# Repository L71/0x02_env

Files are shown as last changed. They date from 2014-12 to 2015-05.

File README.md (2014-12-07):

0x02_env
========

Eurorack AD/ASR envelope and CV generator

This module generates a bipolar control voltage in response to a gate/trigger pulse.
The button selects how it responds to an input pulse: Attack-Decay or Attack-Sustain-Release. 
The zero and triggered (peak) levels are separately set anywhere within the output voltage range (-5 - +5 V).

** Work in progress **

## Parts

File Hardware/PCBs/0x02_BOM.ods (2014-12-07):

Qty | Value | Device | Parts | Description
6 | 100n | Ceramic capacitor 2.54mm | C1, C2, C4, C7, C11, C12
3 | 10u | Electrolytic capacitor. | C3, C5, C6 | Must not be more than 11mm high!
2 | 10n | Ceramic capacitor 2.54mm | C8, C9 | PWM filtering caps. 1-10nF OK. Lower value -> faster envelopes but more PWM leftovers.
2 | CV_OUT | AUDIO-JACKERTHENVAR | CV_OUT, GATE_THRU | Switching Mono 3.5mm Audio Jack from Erthenvar.
2 | AUDIO-JACKERTHENVAR | AUDIO-JACKERTHENVAR | CV1IN, GATE_IN | Switching Mono 3.5mm Audio Jack from Erthenvar.
2 | 1N4004 | 1N4004 | D1, D2 | 1N4001 also OK.
1 | 78L05Z | 78L05Z | IC1 | Voltage regulator 5V TO92 package
1 | TL072 | TL072P | IC2
1 | 4050N | 4050N | IC3
1 | EURORACK PSU | PINHD-2X5 | JP1 | 2x5 2.54mm pin header for Eurorack power connection. Mounted on back of PCB.
1 | Green | LED5MM | LED1 | 5mm clear lens 6000mcd R16=4,7k
1 | Red | LED5MM | LED2 | 5mm clear lens 7800mcd R13=4,7k
1 | Blue | LED5MM | LED3 | 5mm clear lens 8000mcd R5=10k
5 | 100k | R-EU_0207/2V | R1, R2, R3, R4, R6
5 | 1k | R-EU_0207/2V | R5, R7, R13, R15, R16 | R5, R13, R16 are LED current limiting resistors. Choose wisely! (LED drive voltage is 5V).
1 | 10k | R-EU_0207/2V | R8
4 | 10k | POT_USVERTICAL | R9, R10, R11, R12 | ALPS 10K lin PCB mount potentiometer Mouser Pt No 688-RK09D1130C2P
1 | TL2285 | TL2285 | SW1 | E-Switch TL2285 (PCB switch, latching) Mouser Pt.No. 612-TL2285EE300Q
1 | ATTINY84-20PU | ATTINY84ATTINY84-20PU | U$1 | Atmel ATtiny84 MCU DIL14
1 | AVR_ISP | AVR_SPI_PRG_6PTH | U$2 | AVR ISP 6 Pin header. Mounted on back of PCB.
1 | cap for switch SW1 |  |  | Mouser part no 612-1RWHT, 612-1R-BK, 612-1R-RD
4 | knobs for potentiometers |  |  | The pots mentioned have 6mm D-shaped shafts. Small knobs recommended, panel is a bit crowded.
1 | 0x02 PCB
1 | 0x02 Front panel |  |  | Prototype panels done with Ponoko “Medium Grey transparent Acrylic GS”. Note: no LED holes in panel.
4 | 12mm M3 spacer bolts |  |  | For use between front panel and PCB
4 | 6mm M3 screws |  |  | Screws -> front panel -> 12mm spacer bolts <- PCB <- Nuts.
4 | M3 nuts

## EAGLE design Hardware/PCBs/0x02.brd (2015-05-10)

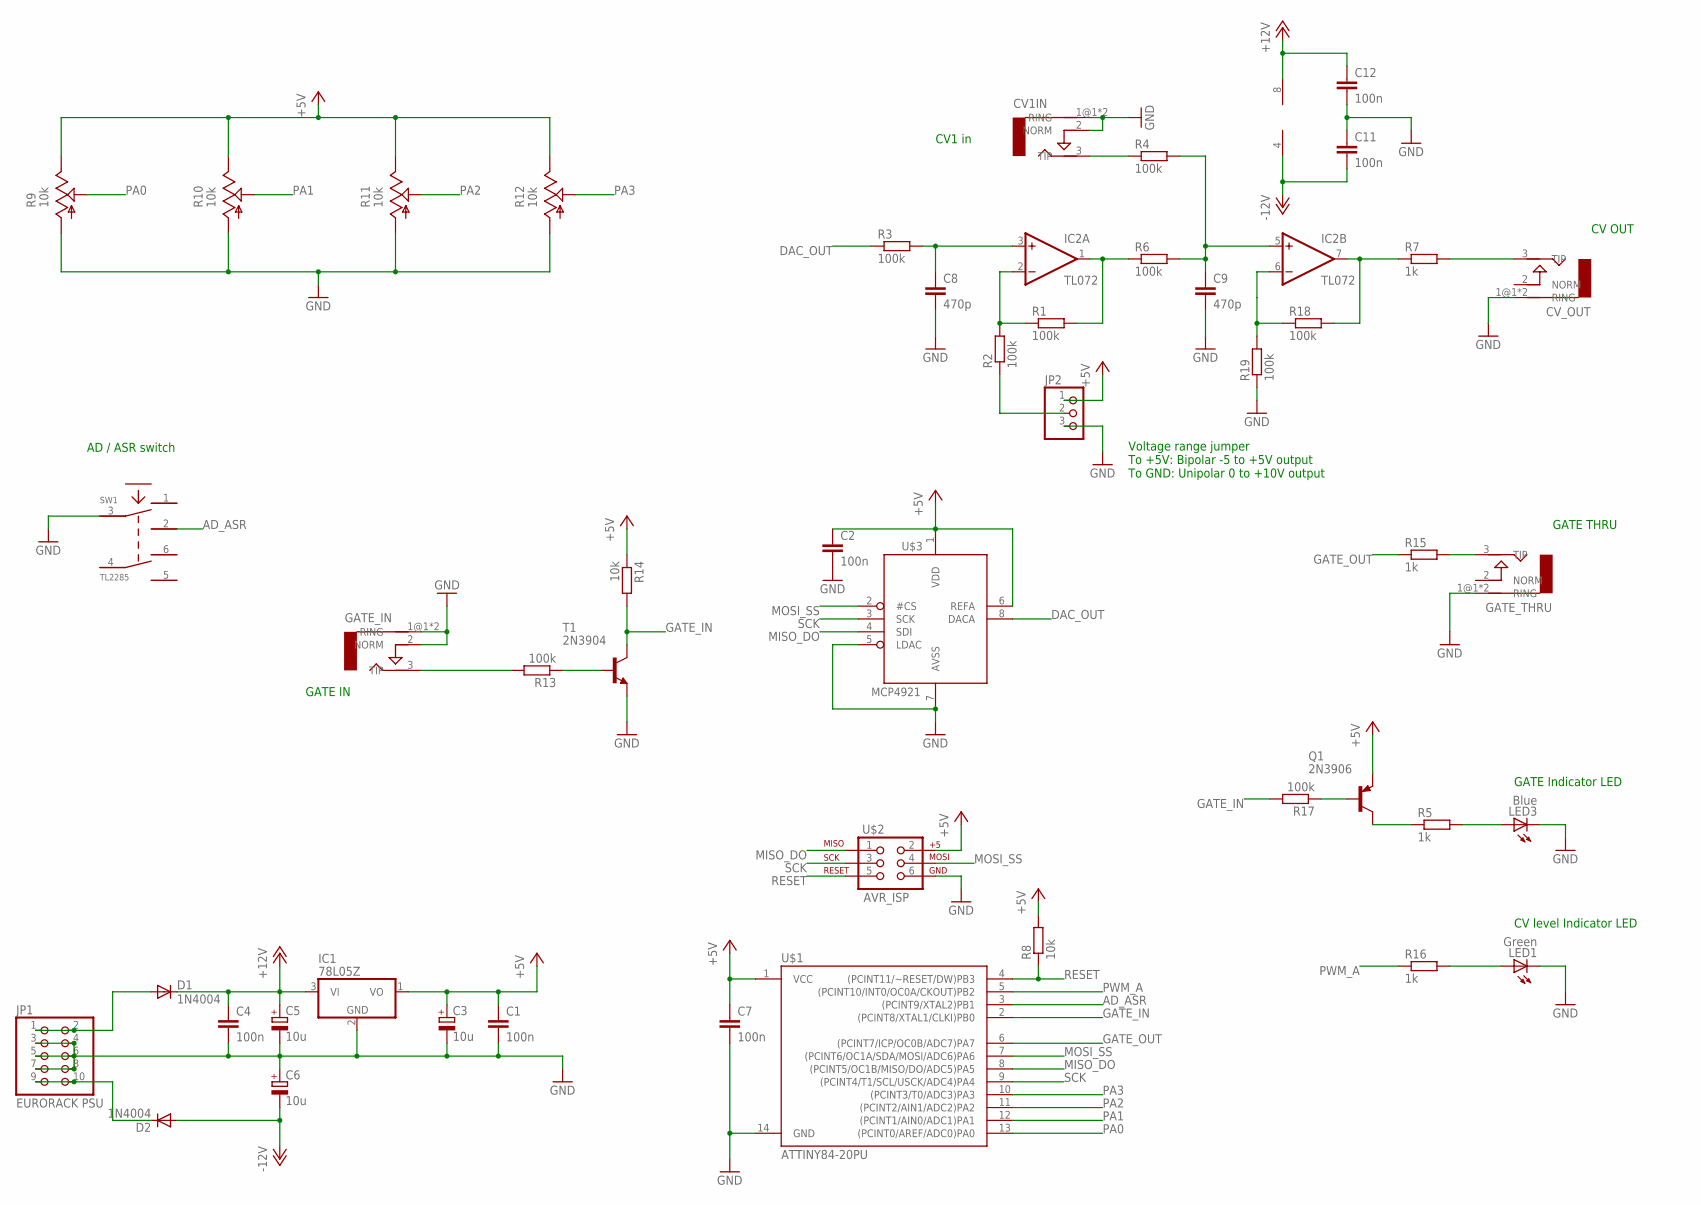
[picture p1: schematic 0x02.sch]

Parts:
C1, C2, C4, C7, C11, C12: 100n; C025-025X050
C3, C5, C6: 10u; E2,5-5
C8, C9: 470p; C025-025X050
CV1IN: AUDIO-JACKERTHENVAR; ERTHENVAR-JACK
CV_OUT: CV_OUT; ERTHENVAR-JACK
D1, D2: 1N4004; DO41-10
GATE_IN: AUDIO-JACKERTHENVAR; ERTHENVAR-JACK
GATE_THRU: CV_OUT; ERTHENVAR-JACK
IC1: 78L05Z; TO92
IC2: TL072; DIL08
JP1: EURORACK PSU; 2X05
JP2: PINHD-1X3; 1X03
LED1: Green; LED5MM
LED3: Blue; LED5MM
Q1: 2N3906; TO92
R1, R2, R3, R4, R6, R13, R17, R18, R19: 100k; 0207/2V
R5, R7, R15, R16: 1k; 0207/2V
R8, R14: 10k; 0207/2V
R9, R10, R11, R12: 10k; ALPS_POT_VERTICAL
SW1: TL2285; TL2285_PCB
T1: 2N3904; TO92
U$1: ATTINY84-20PU; DIL14
U$2: AVR_ISP; 2X3
U$3: MCP4921; DIL08

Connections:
+5V: C1.1, C2.1, C3.+, C7.1, IC1.1 (VO), JP2.1, Q1.3 (E), R8.2, R9.P$1 (E), R10.P$1 (E), R11.P$1 (E), R12.P$1 (E), R14.1, U$1.1 (VCC), U$2.2, U$3.1 (VDD), U$3.6 (REFA)
+12V: C4.1, C5.+, C12.1, D1.C, IC1.3 (VI), IC2.8 (V+)
+12V_IN: D1.A, JP1.1, JP1.2
-12V: C6.-, C11.2, D2.A, IC2.4 (V-)
-12V_IN: D2.C, JP1.9, JP1.10
AD_ASR: SW1.2, U$1.3 ((PCINT9/XTAL2)PB1)
DAC_OUT: R3.1, U$3.8 (DACA)
GATE_IN: R14.2, R17.2, T1.1 (C), U$1.2 ((PCINT8/XTAL1/CLKI)PB0)
GATE_OUT: R15.1, U$1.6 ((PCINT7/ICP/OC0B/ADC7)PA7)
GND: C1.2, C2.2, C3.-, C4.2, C5.-, C6.+, C7.2, C8.2, C9.2, C11.1, C12.2, CV1IN.1@1 (RING), CV1IN.1@2 (RING), CV1IN.2 (NORM), CV_OUT.1@1 (RING), CV_OUT.1@2 (RING), GATE_IN.1@1 (RING), GATE_IN.1@2 (RING), GATE_IN.2 (NORM), GATE_THRU.1@1 (RING), GATE_THRU.1@2 (RING), IC1.2 (GND), JP1.3, JP1.4, JP1.5, JP1.6, JP1.7, JP1.8, JP2.3, LED1.K (C), LED3.K (C), R9.P$3 (A), R10.P$3 (A), R11.P$3 (A), R12.P$3 (A), R19.1, SW1.3, T1.3 (E), U$1.14 (GND), U$2.6, U$3.5 (LDAC), U$3.7 (AVSS)
MISO_DO: U$1.8 ((PCINT5/OC1B/MISO/DO/ADC5)PA5), U$2.1, U$3.4 (SDI)
MOSI_SS: U$1.7 ((PCINT6/OC1A/SDA/MOSI/ADC6)PA6), U$2.4, U$3.2 (#CS)
unnamed: R13.1, T1.2 (B)
unnamed: Q1.1 (C), R5.1
unnamed: LED3.A, R5.2
unnamed: Q1.2 (B), R17.1
unnamed: C8.1, IC2.3 (+IN), R3.2
unnamed: JP2.2, R2.1
unnamed: GATE_THRU.3 (TIP), R15.2
unnamed: GATE_IN.3 (TIP), R13.2
unnamed: IC2.2 (-IN), R1.1, R2.2
unnamed: IC2.1 (OUT), R1.2, R6.1
unnamed: CV_OUT.3 (TIP), R7.2
unnamed: C9.1, IC2.5 (+IN), R4.2, R6.2
unnamed: IC2.6 (-IN), R18.1, R19.2
unnamed: CV1IN.3 (TIP), R4.1
unnamed: IC2.7 (OUT), R7.1, R18.2
unnamed: LED1.A, R16.2
PA0: R9.P$2 (S), U$1.13 ((PCINT0/AREF/ADC0)PA0)
PA1: R10.P$2 (S), U$1.12 ((PCINT1/AIN0/ADC1)PA1)
PA2: R11.P$2 (S), U$1.11 ((PCINT2/AIN1/ADC2)PA2)
PA3: R12.P$2 (S), U$1.10 ((PCINT3/T0/ADC3)PA3)
PWM_A: R16.1, U$1.5 ((PCINT10/INT0/OC0A/CKOUT)PB2)
RESET: R8.1, U$1.4 ((PCINT11/~RESET/DW)PB3), U$2.5
SCK: U$1.9 ((PCINT4/T1/SCL/USCK/ADC4)PA4), U$2.3, U$3.3 (SCK)

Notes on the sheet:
CV OUT
GATE THRU
GATE IN
CV1 in
AD / ASR switch
CV level Indicator LED
GATE Indicator LED
Voltage range jumper To +5V: Bipolar -5 to +5V output To GND: Unipolar 0 to +10V output

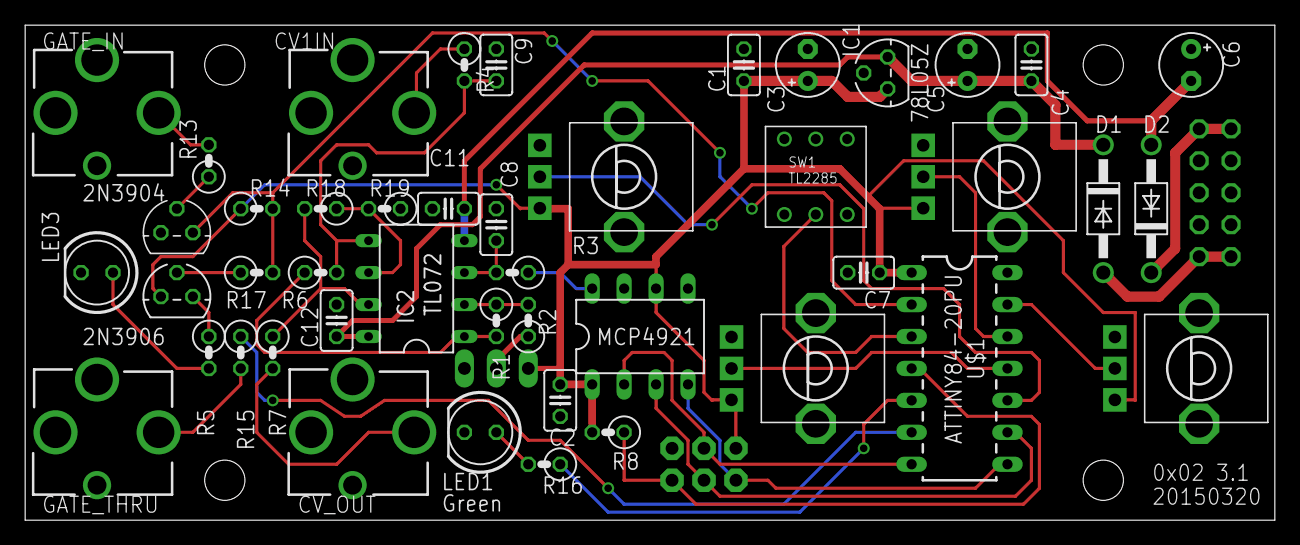
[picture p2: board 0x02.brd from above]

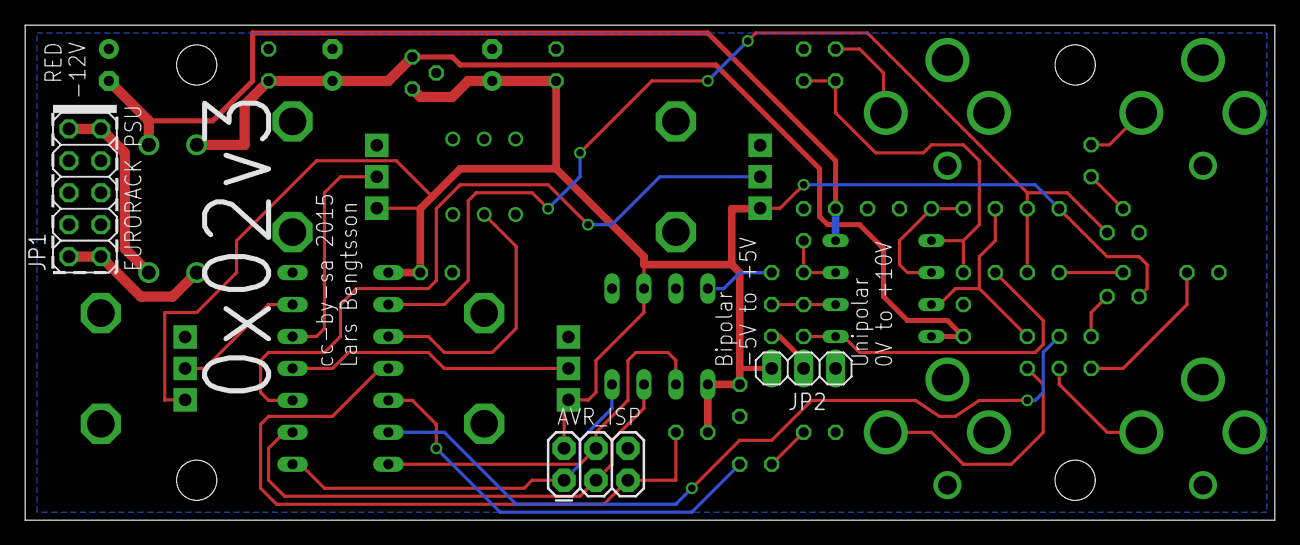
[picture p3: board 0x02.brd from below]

Board: 2 copper layers, 99.4 x 39.4 mm, 48 parts (3 on the bottom side), 35 nets.

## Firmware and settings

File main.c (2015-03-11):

#define F_CPU 8000000UL

#include <avr/io.h>
#include <util/delay.h>
#include <avr/interrupt.h>

#include "pwm_timer.h"
#include "adc.h"
#include "spi.h"

int main() {

	// setup input IO pins (PB0 / PB1 are inputs by default, just set PB1 pull-up)
	PORTB |= 0x02;
	
	// also set PA7 as output (GATE THRU output signal)
	DDRA |= _BV(PA7);


	pwm_timer_setup();

	setup_spi();

	adc_setup();

	run_adc_timer();

    // Enable interrupts for all. GO! =)
    SREG |= 0x80 ;
	
    // main loop
    while ( 1 )  {
		// OCR0A = 0;
        _delay_ms(3);
		// OCR0A = 255;
		_delay_ms(2);
    }
  
}

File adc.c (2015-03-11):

// PWM timer setup 

#include <avr/io.h>
#include <avr/interrupt.h>

#include "spi.h"

// ADC latest values
struct adc_data {
	uint8_t attack, level_off, decay, level_on ;
} adc ;

// state machine tracking
#define ATTACK	1
#define DECAY	2
#define LOW		3
#define HIGH	4
volatile uint8_t env_complete = 0;

// current output env value
uint16_t currentlevel; 


void adc_setup() {
	// enable ADC, clock prescaler = /64
	ADCSRA |= (1<<ADEN) | (1<<ADPS2) | (1<<ADPS0) ;
	
	// left adjust result
	ADCSRB |= (1<<ADLAR);
	
	// disable digital IO on used ADC pins
	DIDR0 = 0b00001111;	
	
	// Go! =)
	ADCSRA |= (1<<ADSC) ;
}

void run_adc_timer() {	// enable 16bit timer1 + interrupts
	
	// OCR1AH = 0x1f; // 8MHz, divider 8000 -> 1KHz timer
	// OCR1AL = 0x40;
	
	OCR1AH = 0x03; // 8MHz, divider 1000 -> 8KHz timer
	OCR1AL = 0xe8;
	
	// clear on OCR1A, clock prescaler 1. 
	TCCR1B |= (1<<WGM12) | (1<<CS10) ;
	// TCCR1B |= (1<<WGM12) | (1<<CS10) | (1<<CS11) ;  // presc. /64
	
	// enable OCR1A interrupt
	TIMSK1 |= (1<<OCIE1A);
}

inline void setpwm(uint8_t value) {  // update PWM output registers
	if ( value == 0) {
		value = 1;
	}
	if ( value == 255 ) {
		value = 254;
	}
	OCR0A=value;
	OCR0B=value;
	spi_write_word(value << 4);
}

void env_update(uint8_t rate, uint8_t targetlevel_8) {
	
	uint16_t chrate;
	uint16_t targetlevel = (uint16_t)targetlevel_8 * 256 ;
	
	chrate=(uint16_t)rate; // make change rate 16bit
	
	// accelerate envelope change rate expnentially
	if (chrate == 0) {
		chrate=1;
	}
	if (chrate > 128) {
		chrate = chrate+((chrate-128)*2);
	}
	if (chrate > 192) {
		chrate = chrate+((chrate-192)*2);
	}
	if (chrate > 220) {
		chrate = chrate+((chrate-220)*2);
	}


	if ( currentlevel == targetlevel) {
		env_complete=1;
	} else {
		if ( currentlevel < targetlevel ) {	// env going up 
			if ( currentlevel <= (targetlevel-chrate)) {  // check, pass target level?
				currentlevel += chrate;
			} else {
				currentlevel = targetlevel;
				env_complete=1;
			} 
		} 
		if ( currentlevel > targetlevel ) { // env going down
			if ( currentlevel >= (targetlevel+chrate) ) { // check, pass target level?
				currentlevel -= chrate;
			} else {
				currentlevel = targetlevel;
				env_complete=1;
			}
		}
	}
	setpwm( (uint8_t) (currentlevel >> 8) );
}

void state_env() {
	
	uint8_t gate_went_high=0 ;	// event: gate went high
	uint8_t gate_went_low=0 ;	// event: gate went low
	
	static uint8_t prev_gate_level ; // saves previous gate level 
	
	uint8_t gate ; // gate input value
	uint8_t mode_gate ;	// gated or triggered mode?
	static uint8_t stage = LOW ; 	// curremt ENV stage
	
	gate = ( ~PINB & 0x01 );	// check gate input pin
	mode_gate = ( PINB & 0x02 ); // 0=trig, 1=gate
	
	if ( prev_gate_level == 0 ) {	
		if (gate) { // gate went low->high
			gate_went_high = 1 ;
			prev_gate_level = 1;
		}
	} else {	// prev state high, low now... 
		if (! gate) {
			gate_went_low = 1 ; 
			prev_gate_level = 0 ;
		}
	}
	
	// copy gate state to GATE THRU output (PA7)
	if (gate) {
		PORTA |= _BV(PA7);
	} else {
		PORTA &= ~_BV(PA7);
	}
	
	
	// state machine 
	switch (stage) {
	
		case LOW:
			if (gate_went_high) {
				env_complete=0;
				stage=ATTACK;
			} 
			setpwm(adc.level_off);
			currentlevel=adc.level_off*256;
			break;
			
		case ATTACK:
			env_update(adc.attack, adc.level_on);
			if (mode_gate) {	// gated mode
				if (env_complete) {	
					stage=HIGH;	// go to HIGH if env timer completed
					env_complete=0;
				}
				if (gate_went_low) {	// always go directly to DECAY if gate->low
					stage=DECAY;
					env_complete=0;
				}
			} else {  	// trigger mode
				if (env_complete) {
					stage=DECAY;	// go to DECAY if env timer completed
					env_complete=0;
				}
			}

			break;
			
		case HIGH:
			setpwm(adc.level_on);
			currentlevel=adc.level_on*256;
			if (gate_went_low) {	// go to DECAY if gate->low
				env_complete=0;
				stage=DECAY;
			}
			break;
			
		case DECAY:
			env_update(adc.decay, adc.level_off);
			if (gate_went_high) {	// always back to ATTACK if gate->high.
				stage=ATTACK;
				env_complete=0;
			}
				
			break;
	}	
	
}


ISR(TIM1_COMPA_vect) {
	
	static uint8_t adc_chan=0;

	
	uint8_t chan_mask=0x03; // use 4 channels (0-3).
	uint8_t adc_in = ADCH;
	
	switch (adc_chan) {
		case 0 :	// chan 0
			// adc.attack = adc_in;
			adc.level_on = adc_in;
			break;
		case 1 :	// chan 1
			// adc.level_off = adc_in;
			adc.attack = adc_in;
			break;
		case 2 :	// chan 2
			// adc.decay = adc_in;
			adc.level_off = adc_in;
			break;
		case 3 :	// chan 3
			// adc.level_on = adc_in;
			adc.decay = adc_in;
			break;
	}
	
	// OCR0B = adc.attack;

	adc_chan = ((adc_chan+1) & chan_mask ) ;
	
	// update ADMUX register
	ADMUX &= 0xf0;	// reset channel bits
	ADMUX |= adc_chan ;
	
	// start next conversion
	ADCSRA |= (1<<ADSC) ;
	
	// update ENV state machine 
	state_env();

}

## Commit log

2014-12-07 Added PCBEagle files + Panels.
    [0x02.brd, 0x02.sch]
2014-12-07 Added BOM spreadsheet.
    [0x02_BOM.ods]
2015-02-01 Don't track Eagle backup files
2015-03-11 Checkin of code & PCB for version 3 with DAC instead of PWM output.
    [0x02.brd, 0x02.sch]
2015-03-20 Added jumper to set voltage output range, -5V to +5V or 0-+10V.
    [0x02.brd, 0x02.sch]
2015-05-10 Make voltage mixer into a true voltage adder (ext cv in tied to GND when unused, and 2x gain in output amp).
    [0x02.brd, 0x02.sch]

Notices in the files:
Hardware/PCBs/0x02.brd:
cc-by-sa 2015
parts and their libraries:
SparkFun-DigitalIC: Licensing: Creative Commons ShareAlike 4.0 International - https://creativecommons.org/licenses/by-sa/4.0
